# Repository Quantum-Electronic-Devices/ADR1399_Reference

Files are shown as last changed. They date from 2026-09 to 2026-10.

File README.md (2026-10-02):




# ADR1399 Sub-ppm Reference Voltage

This repository contains the KiCAD PCB project files for a sub-ppm temperature coefficient __negative voltage reference__ used in the [DgDrive](https://qed.gmbh/en/products/electronics/dgdrive/) laser current driver.

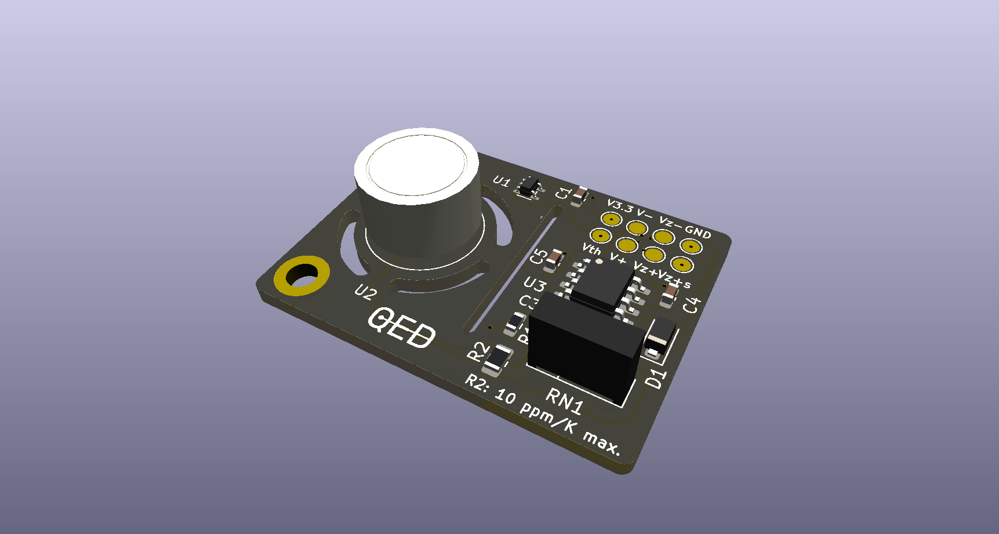
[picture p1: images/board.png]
ADR1399 reference board


## Circuit description

ADR1399 reference board circuit

This circuit utilizes the excellent [ADR1399](https://www.analog.com/en/products/adr1399.html)/[LM399](https://www.analog.com/en/products/lm399.html) voltage reference and outputs an amplified voltage of either -10 V or -15 V. There is no option to trim the output voltage as the absolute value is not that important, but stability is. The output voltage will be 10 V / 15 V __below__ the positive pin of the Zener diode.

The design is a self-biased circuit, which means the Zener diode bias current is produced by the Zener voltage and therefore as stable as the reference (neglecting the influence of the bias current on the Zener voltage as it is negligible). In order to keep the Zener self-heating of the diode as low possible, a Zener current of a little more than 3 mA was chosen for the [ADR1399](https://www.analog.com/en/products/adr1399.html).

Reference table for choosing the resistor values:

|Voltage | R1 | RN1 |
|---|---|---|
|-10 V | 3k | 20k /  9k  |
|-15 V | 7.89k | 17k / 20k |

Different values are possible as well, but these values were readily available on Farnell/Mouser. When choosing a value for R1, choose a value as close as possible but always __less than or equal__ to the value given. This ensures, that the Zener current is at least 1 mA.

Single supply operation is possible as long the output voltage is larger than 0.1 V (referenced to GND).

## Design Files
### For production
The design files required for the PCB production and assembly can be found on the [releases](../../releases) page and include the following resources:

- Schematics as a PDF
- Gerber files
- Pick & place position files
- Bill of materials as a CSV file and also as an interactive HTML version

The latest revision of those files can be found [here](../../releases/latest).

#### Variants
Two variants of the design files are provided for the user. There is a so-called *default* variant and a *PCBA* (Printed Circuit Board Assembly) variant.

##### Default variant
The default variant contains the full set of components and should be used for hand assembly when a set of binned and tested components is available. It includes both the Zener reference and resistive divider which need to be tested for popcorn noise and drift before installation.

##### PCBA variant
The PCBA variant should be used when sending the boards to the PCB manufacturer for assembly as they do not contain the [ADR1399](https://www.analog.com/en/products/adr1399.html)/[LM399](https://www.analog.com/en/products/lm399.html) Zener reference and the precision resistor array to amplify the output voltage. These components need to be binned prior to installation and should therefore not be placed by the board house.

### For editing
To work on the [KiCad](https://www.kicad.org/) design files, a number of external libraries are needed. Those libraries show up as empty folders in the zip file, because they are not included in the release, but must be downloaded separately from the links given [below](#related-repositories). This can be avoided by checking out the whole repository using git. This way the libraries will be downloaded as well. Use the following command to clone the git repository along with the submodules  using the `--recurse-submodules` flag.
```
git clone --recurse-submodules https://github.com/Quantum-Electronic-Devices/ADR1399_Reference
```

## Related Repositories
See the following repositories for more information as these are part of the [design files](#design Files).

- [KiCad footprints](https://github.com/PatrickBaus/footprints.pretty)
- [KiCAD 3D models](https://github.com/PatrickBaus/footprints.3dshapes)
- [KiCAD schematic libraries](https://github.com/PatrickBaus/KiCad-libraries)

## Versioning
We use [SemVer](http://semver.org/) for versioning. For the versions available, see the [tags](../../tags) available for this repository.

- MAJOR versions in this context mean a breaking change to the external interface of the hardware like different connectors or functions.
- MINOR versions contain changes to the hardware that only affect the inner workings of the circuit, but otherwise the performance is unaffected.
- PATCH versions do not affect the schematics or invalidate older bill of materials. These changes may include updated components (to replace obsolete parts for example), an updated silkscreen, or fixed typos.

## License
This work is released under the CERN-OHL-W
See [https://ohwr.org/cern_ohl_w_v2.pdf](https://ohwr.org/cern_ohl_w_v2.pdf) or the included LICENSE file for more information.

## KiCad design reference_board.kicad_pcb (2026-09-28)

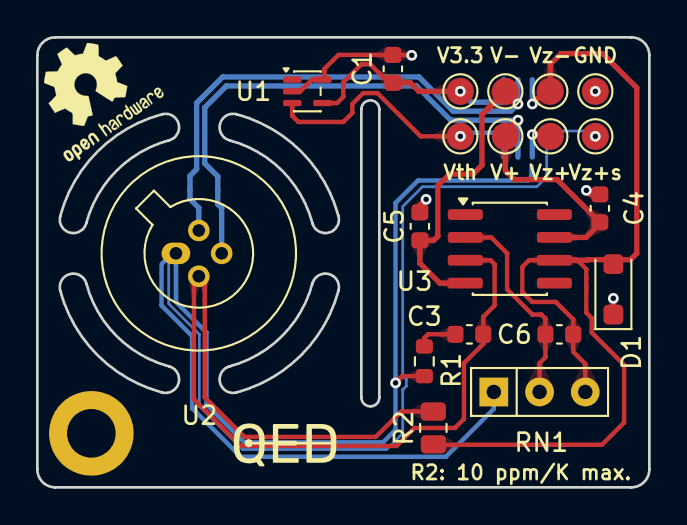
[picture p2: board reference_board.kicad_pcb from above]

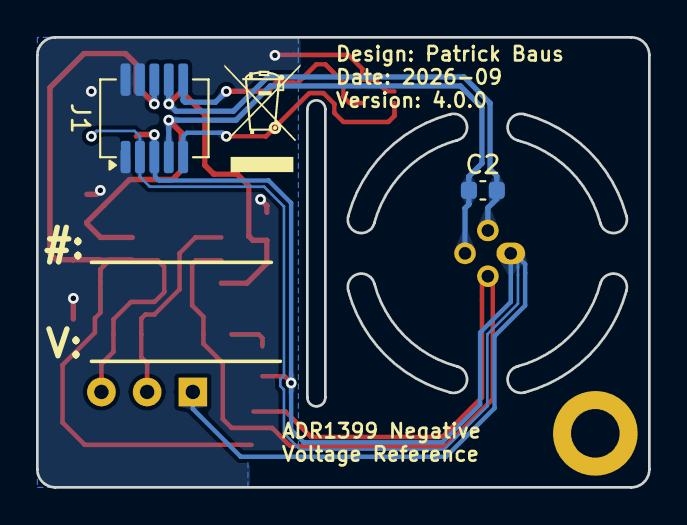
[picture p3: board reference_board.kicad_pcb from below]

Board: 2 copper layers, 34.0 x 25.0 mm, 31 parts (5 on the bottom side), 15 nets.

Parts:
C1, C4, C5: 100n; C_0603_1608Metric
C2, C3: 1u; C_0603_1608Metric
C6: 10n; C_0603_1608Metric
D1: BAS116; D_SOD-123F
H1: MountingHole; MountingHole_2.7mm_M2.5_DIN965_Pad
J1: Conn_02x05_Counter_Clockwise; Molex_SlimStack_53307-1071_2x05_P0.80mm_Vertical
LOGO1: Logo_Open_Hardware_Small; OSHW-Logo2_7.3x6mm_SilkScreen
LOGO2: Logo_QED; QED-logo_small
NT1: NET-TIE; NET-TIE-0.15mm
NT2, NT3, NT4, NT5: NET-TIE; NET-TIE-0.25mm
R1: 5.1R; R_0603_1608Metric
R2: 7.5K; R_0805_2012Metric
RN1: 17k/20k; R_Array_Box3_L7.5mm_W2.5mm_P2.54mm_Vishay_300144
SYM2: SYM_WEEE; WEEE-Logo_4.2x6mm_SilkScreen
TP1, TP2, TP3, TP4, TP5, TP6, TP7, TP8: TestPoint; TestPoint_Pad_D1.5mm
U1: TMP236; SOT-353_SC-70-5
U2: ADR1399; Analog_TO-46-4_ThermalShield
U3: LT1001; SOIC-8_3.9x4.9mm_P1.27mm

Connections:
/V3.3: C1.1, J1.6, TP4.1 (1_1), U1.4 (V_{DD})
/V_{th}: J1.5, TP8.1 (1_1), U1.3 (V_{OUT})
/Voltage Reference/V+: C2.1, C4.1, J1.4, TP7.1 (1_1), U2.3, U3.7 (V+)
/Voltage Reference/V-: C2.2, C5.1, J1.7, TP3.1 (1_1), U2.4, U3.4 (V-)
/Voltage Reference/V_zener+_force: J1.3, NT1.2, NT5.2, R1.1, TP6.1 (1_1), U2.1
/Vout: D1.2 (A), J1.8, NT3.2, NT4.1, TP2.1 (1_1), U3.6
/Zener+_sense: J1.2, NT1.1, TP5.1 (1_1)
GND: C1.2, C4.2, C5.2, D1.1 (K), J1.1, J1.9, J1.10, TP1.1 (1_1), U1.2 (GND), U1.5 (GND)
unnamed: C3.1, R1.2
unnamed: C6.1, NT4.2, RN1.3
unnamed: NT2.1, R2.2
unnamed: NT3.1, R2.1
unnamed: NT5.1, RN1.1
unnamed: C3.2, NT2.2, U2.2, U3.3 (+)
unnamed: C6.2, RN1.2, U3.2 (-)

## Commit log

2026-09-28 Loosen design specs of the board thickness a little from +-0.13 mm to +-0.16 mm. (#3)
    This change eases manufacturing and does not affect performance.
    [reference_board.kicad_pcb]
2026-09-28 Make the silkscreen colour less transparent to get the looks closer to the finished product. (#4)
    [reference_board.kicad_pcb]
2026-09-28 Exlude more filetypes from git. (#5)
    - Add specific file exclusion rules for step files in the root folder
    - Exclude gerber files project wide
2026-09-28 Mirror the board-to-board connector to match a prototyp board.
    [reference_board.kicad_pcb, reference_board.kicad_sch]
2026-10-02 Update/connector (#1)
    * Replaced connector J1 with Molex SlimStack 53307-1071.
    - Updated to KiCAD 10
    - Changed BAS116 diode D1 footprint to SOD-123F due to availability of parts
    - Added QED logo
    - Removed most references to LM399. The ADR1399 is now the default. LM399 is mentioned as option.
    - Added more details for different zener voltage configurations
    - Added WEEE logo
    - Fixed label on silkscreen refering to R1 instead of R2. It now reads 'R2: 10 ppm/K max.'
    * Change standoff to WE 9774045151R.
    * Changed silkscreen colour to black
    * Bump version to 4.0.0
    * Updated symbol
    - Added WEEE logo
    * Update readme
    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
    [LM399.kicad_sch, Zener.kicad_sch, reference_board.kicad_pcb]

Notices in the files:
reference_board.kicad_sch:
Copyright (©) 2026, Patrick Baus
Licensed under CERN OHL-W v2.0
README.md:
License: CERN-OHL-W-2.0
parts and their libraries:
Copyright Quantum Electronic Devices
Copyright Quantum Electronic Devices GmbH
